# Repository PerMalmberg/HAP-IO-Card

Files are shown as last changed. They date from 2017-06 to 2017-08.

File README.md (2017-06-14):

# HAP I/O Card
Input/output card for use in automation

## Design limits
12V maximum voltage.

## Inputs

### Analog inputs

On-board potentiometers as voltage dividers, allowing for adjustable balanced lines used in alarm systems.
> Will fixed resistors do the trick?

### Digital Inputs

* Optocouplers to provide isolation.
* On-board rotary switch to set number of inputs.
* On-board rotary switch to set unit MQTT address.

> Can it be done so that from a software perspective they are always high/true when 'activated'?

## Outputs

### Digital Outputs

* Optocoupler for low current signals.
* Relays for high-current signals.
* Each output shall have a LED indicating current status.

### General in/outputs

UART flashing connectors.
Debugging pins/JTAG

## On-board LEDs
* Power
* Digital outputs
* Digital inputs

## On-board switches
* OTA-enable

## Power supply
12V DC, with onboard 12->5V DC/DC converter.

## Reference Links

http://www.thebox.myzen.co.uk/Tutorial/Protection.html

* Capacitor calculations
  * http://www.electronics-tutorials.ws/rc/rc_1.html

### Components

#### uC ESP32 thing devboard
  * http://www.mouser.se/new/sparkfun/sparkfun-things/

* Common components
  * 10k ohm 0805 0.5W https://www.digikey.se/product-detail/en/panasonic-electronic-components/ERJ-P06F1002V/P16059CT-ND/3982406
  * 100nF 50V https://www.digikey.se/product-detail/en/avx-corporation/08055C104JAT2A/478-3352-1-ND/930144

* Sensor Inputs
  * I/O Expander ADS1115IDGST https://www.digikey.se/product-detail/en/texas-instruments/ADS1115IDGST/296-24934-1-ND/2123298
  * Varistor 39V 0805 https://www.digikey.se/product-detail/en/epcos-tdk/B72510E250K62/495-7453-1-ND/6073112
  * 2k resistor, 0.5W 0805 https://www.digikey.se/product-detail/en/panasonic-electronic-components/ERJ-P06F2001V/P16065CT-ND/3982412
  * Clamping Shottky diodes 60V, 500mA SOD-123 https://www.digikey.se/product-detail/en/stmicroelectronics/STPS0560Z/497-3787-1-ND/691956
  * Protection diode 3A, SMA https://www.digikey.se/product-detail/en/comchip-technology/CDBA3100-HF/641-1747-1-ND/5400721
  * 100 ohm 1/8W 0805 https://www.digikey.se/product-detail/en/yageo/RC0805FR-07100RL/311-100CRCT-ND/730490
  * 1k ohm 0.5W 0805 https://www.digikey.se/product-detail/en/vishay-dale/CRCW08051K00FKEAHP/541-1.00KTCT-ND/2222852

* Digital I/O
  * I/O Expander MCP23017 https://www.digikey.se/product-detail/en/microchip-technology/MCP23017T-E-SO/MCP23017T-E-SOCT-ND/5358289
  * Input      
    * LED Green Vf 2.2, 20mA https://www.digikey.se/product-detail/en/lumex-opto-components-inc/SML-LXR85GC-TR/67-1557-1-ND/304376
    * LED limiting resistor 56R, 1/8W, 0805 https://www.digikey.se/product-detail/en/panasonic-electronic-components/ERJ-6GEYJ560V/P56ACT-ND/42928
    * 100R discharge resistor https://www.digikey.se/product-detail/en/stackpole-electronics-inc/RNCP0805FTD100R/RNCP0805FTD100RCT-ND/2240548
    * 10uF Electrolytic Cap https://www.digikey.se/product-detail/en/panasonic-electronic-components/EEE-1EA100WR/PCE3895CT-ND/766271
    * 1k 3W, 1%, 2512 https://www.digikey.se/product-detail/en/te-connectivity-passive-product/35221K0FT/A121161CT-ND/5245218
    * LTV-354T https://www.digikey.se/product-detail/en/lite-on-inc/LTV-354T/160-1333-1-ND/385797
  * Output
    * Base resistor 470 http://www.digikey.se/scripts/DkSearch/dksus.dll?Detail&itemSeq=230677912&uq=636330538988753686
    * Kickback protection MBR0580 https://www.digikey.se/product-detail/en/micro-commercial-co/MBR0580-TP/MBR0580-TPMSCT-ND/2423306
    * Transistor https://www.digikey.se/product-detail/en/diodes-incorporated/ZXTN25050DFHTA/ZXTN25050DFHCT-ND/1043605
    * LED RED 20mA, Vf 2V https://www.digikey.se/product-detail/en/lumex-opto-components-inc/SML-LXR85IC-TR/67-1556-1-ND/304374
    * LED limiting resistor 68R, 1/8W, 0805 https://www.digikey.se/product-detail/en/stack  pole-electronics-inc/RMCF0805JT68R0/RMCF0805JT68R0CT-ND/1942537

* Power supply
  * Screw terminal 3-way https://www.digikey.se/product-detail/en/te-connectivity-amp-connectors/282834-3/A98334-ND/1153264
  * LM1086-5V https://www.digikey.se/product-detail/en/texas-instruments/LM1086IT-5.0-NOPB/LM1086IT-5.0-NOPB-ND/363580
  * LM1086-3.3V https://www.digikey.se/product-detail/en/texas-instruments/LM1086IT-3.3-NOPB/LM1086IT-3.3-NOPB-ND/363579
  * 100uF 16V 5mm https://www.digikey.se/product-detail/en/nichicon/ULD1C101MED1TD/493-14722-1-ND/6161730
  * Protection diode MBRS360BT3G http://www.digikey.se/scripts/DkSearch/dksus.dll?Detail&itemSeq=230549693&uq=636329621710320791
  * Zener 5.1V SOD-123 https://www.digikey.se/products/en?keywords=1N4733AW-TPMSCT-ND
  * Signal filter https://www.digikey.se/product-detail/en/murata-electronics-north-america/DSS1NB31H104Q91A/490-9806-1-ND/5018359

https://www.facebook.com/groups/SHgruppen/permalink/662561353933301/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

https://www.facebook.com/groups/SHgruppen/permalink/662561353933301/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

## TODO
Fuse 12V and 3.3V PolyFuse

I2C jumpers to disable devices (development feature)?
ESD protection on in/outputs
Display
Flashing wires
Mounting holes http://www.ebay.com/itm/DIN-Rail-Mounting-Carrier-for-72mm-x-110mm-PCB-Housing-Bracket-/131318695142
I2C expansion header
Test points

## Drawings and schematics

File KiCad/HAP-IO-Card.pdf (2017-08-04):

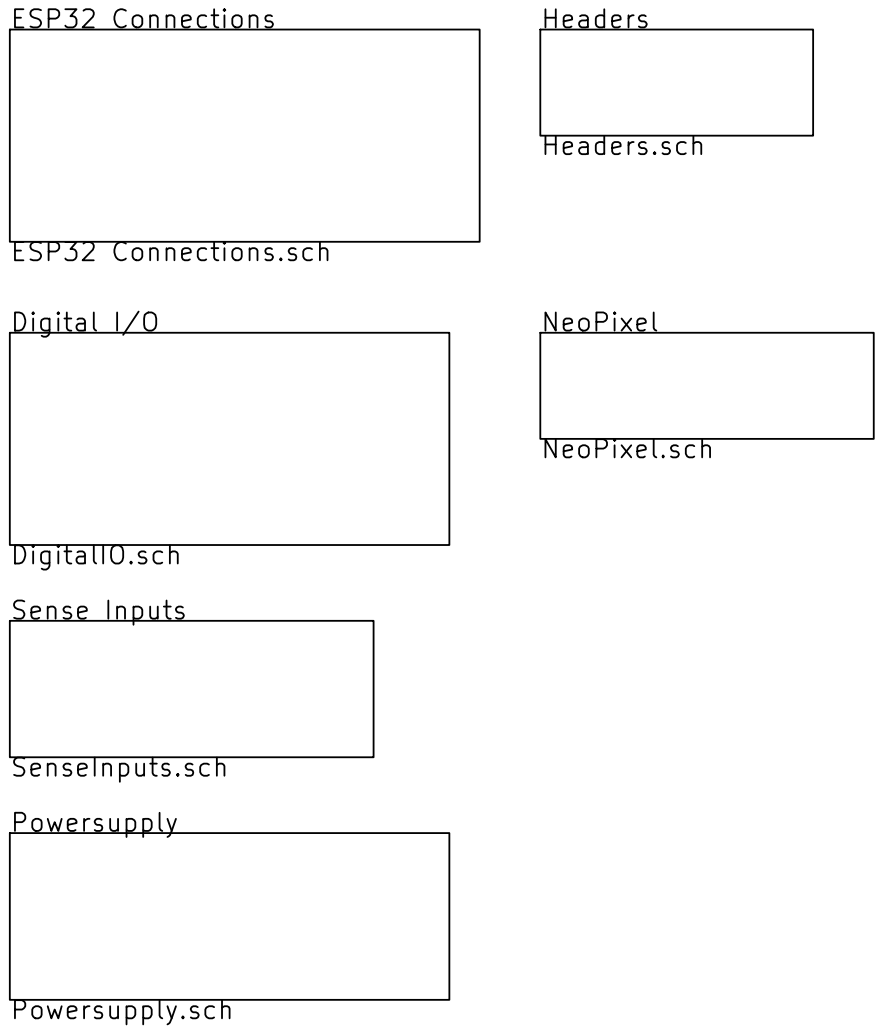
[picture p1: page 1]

https://github.com/PerMalmberg/HAP-IO-Card
File: HAP-IO-Card.sch Sheet: / Author Per Malmberg

Id: 1/7 Title: HAP I/O Card

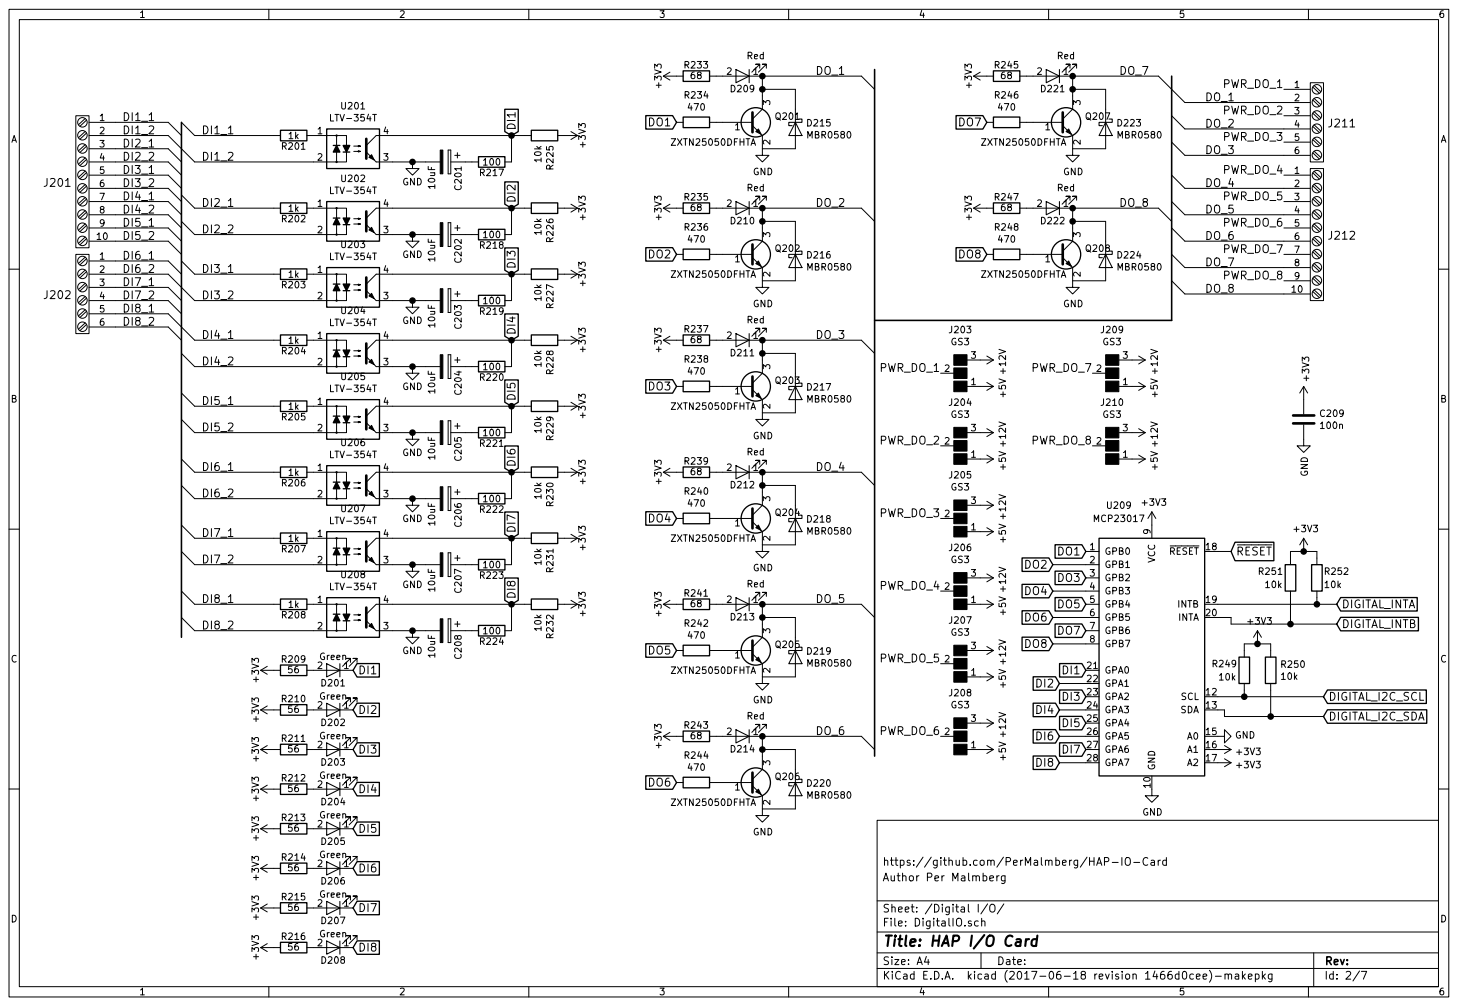
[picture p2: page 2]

1k Select based on input voltage. Max 50mA. 1k should allow for voltages 3.3 - 48V

Sheet: /Digital I/O/
File: DigitalIO.sch
Id: 2/7 Title: HAP I/O Card

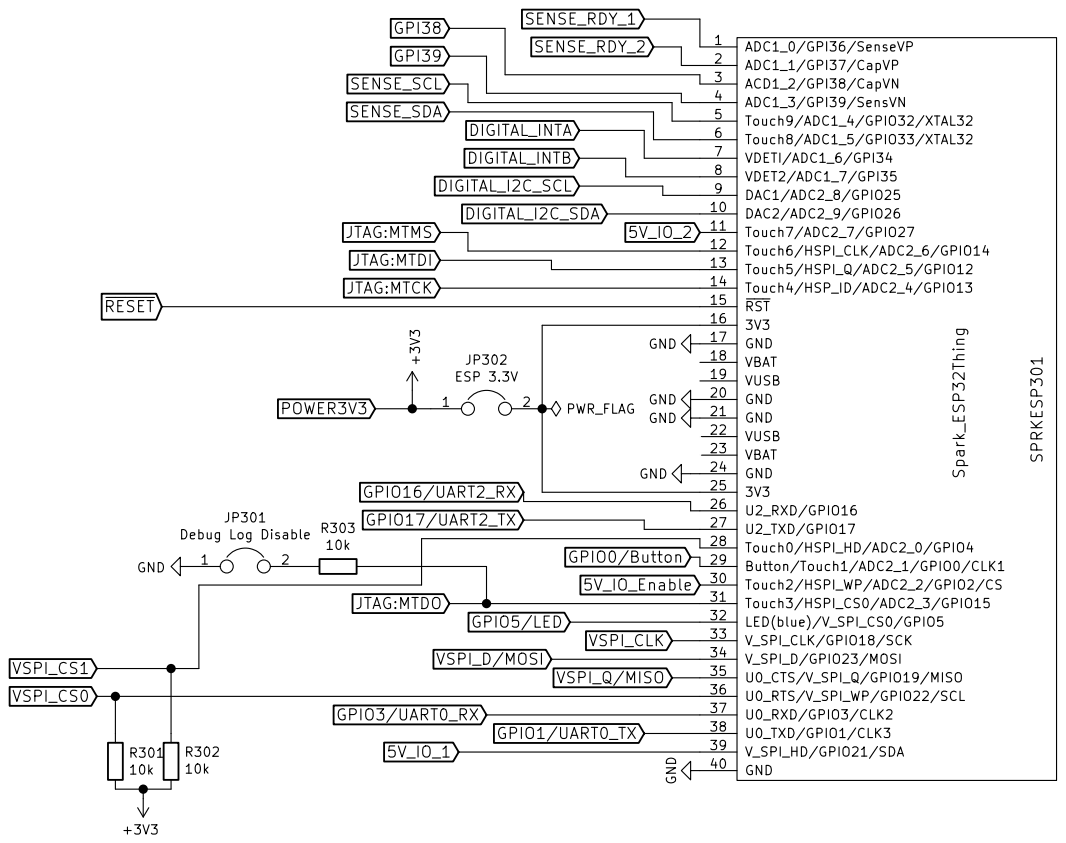
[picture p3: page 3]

The Sparkfun ESP32Thing already
has a 10k pull-up on the reset line.

https://github.com/PerMalmberg/HAP-IO-Card GND GND GND

File: ESP32 Connections.sch Sheet: /ESP32 Connections/ Author Per Malmberg

Id: 3/7 Title: HAP I/O Card

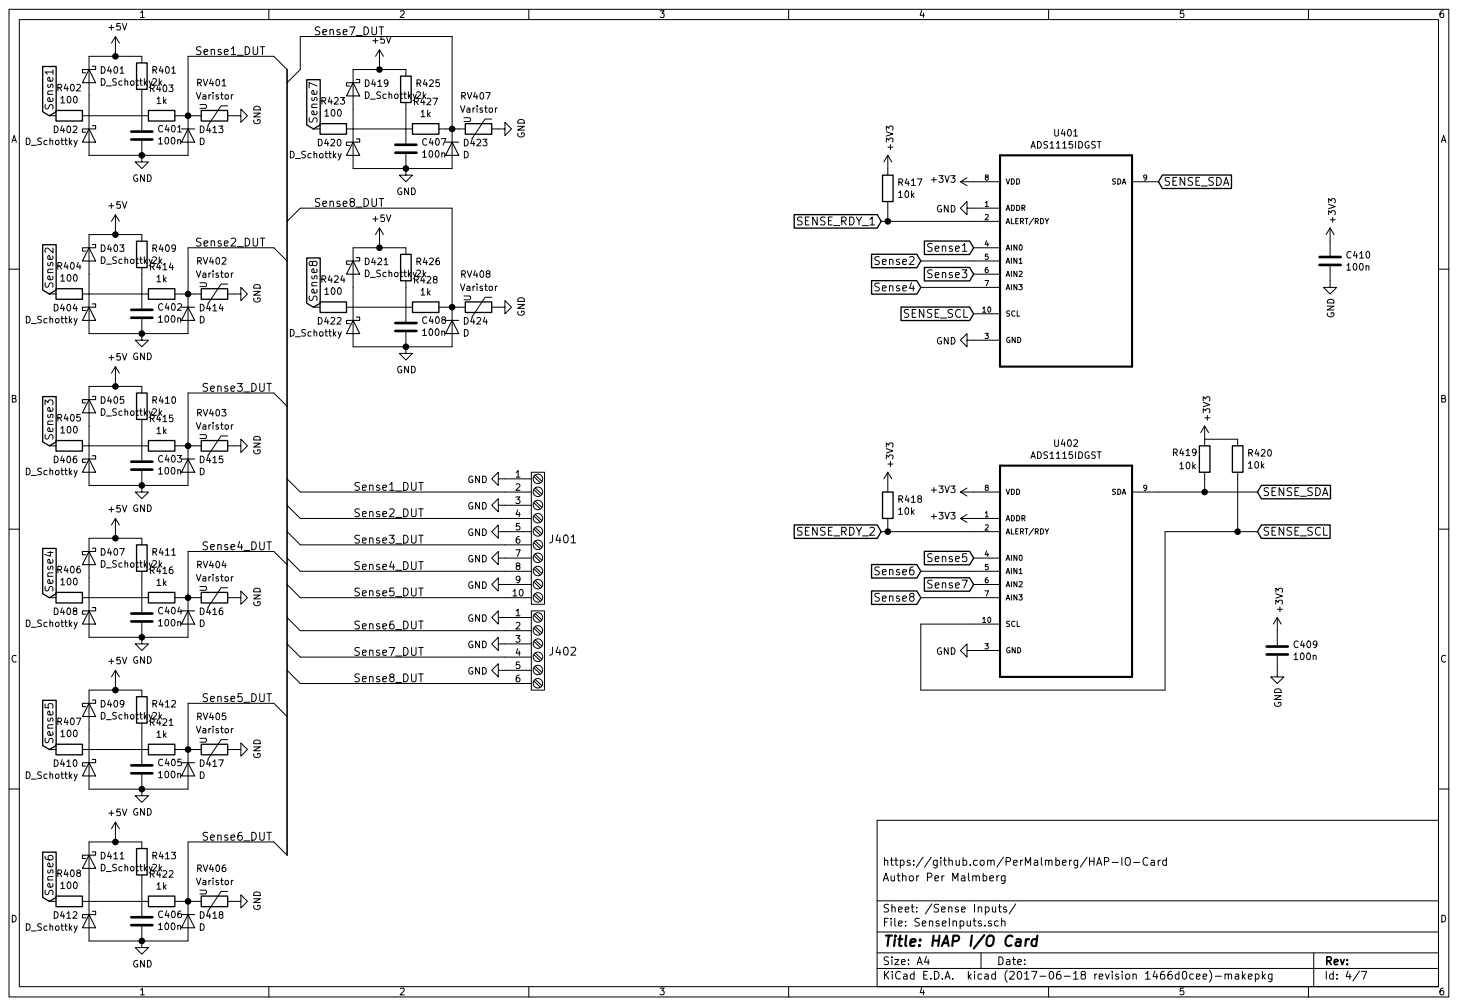
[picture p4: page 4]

https://github.com/PerMalmberg/HAP-IO-Card
Author Per Malmberg

Sheet: /Sense Inputs/
File: SenseInputs.sch
Id: 4/7 Title: HAP I/O Card

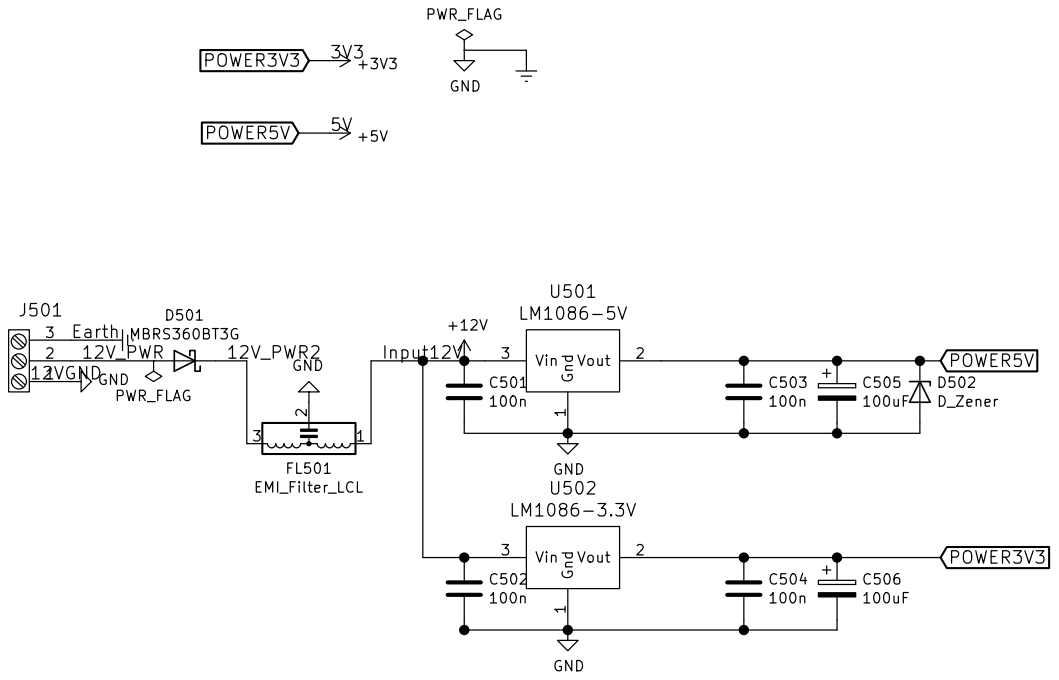
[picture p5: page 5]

+12V Line filter Murata DSN6 Series

prevent rail from going
above nominal value
due to voltage input
from sensor inputs.

https://github.com/PerMalmberg/HAP-IO-Card
Author Per Malmberg

Sheet: /Powersupply/
File: Powersupply.sch
Id: 5/7 Title: HAP I/O Card

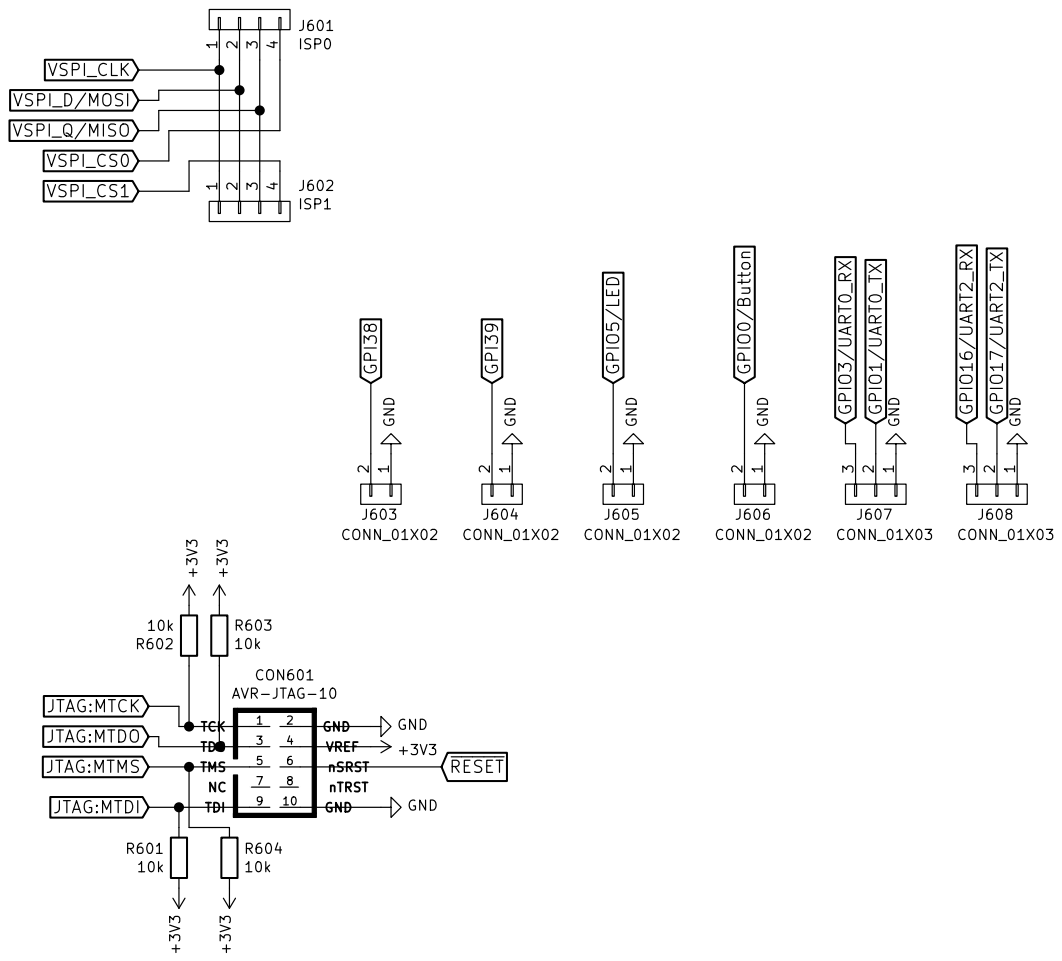
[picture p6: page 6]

https://github.com/PerMalmberg/HAP-IO-Card
File: Headers.sch Sheet: /Headers/ Author Per Malmberg

Id: 6/7 Title: HAP I/O Card

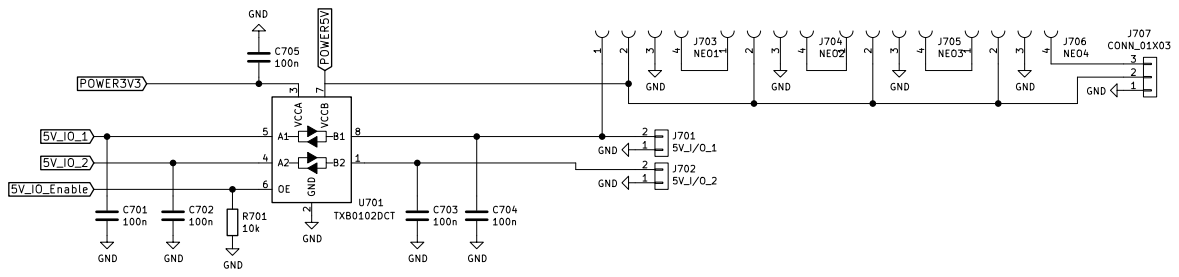
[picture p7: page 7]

File: NeoPixel.sch Sheet: /NeoPixel/ Author Per Malmberg

Id: 7/7 Title: HAP I/O Card

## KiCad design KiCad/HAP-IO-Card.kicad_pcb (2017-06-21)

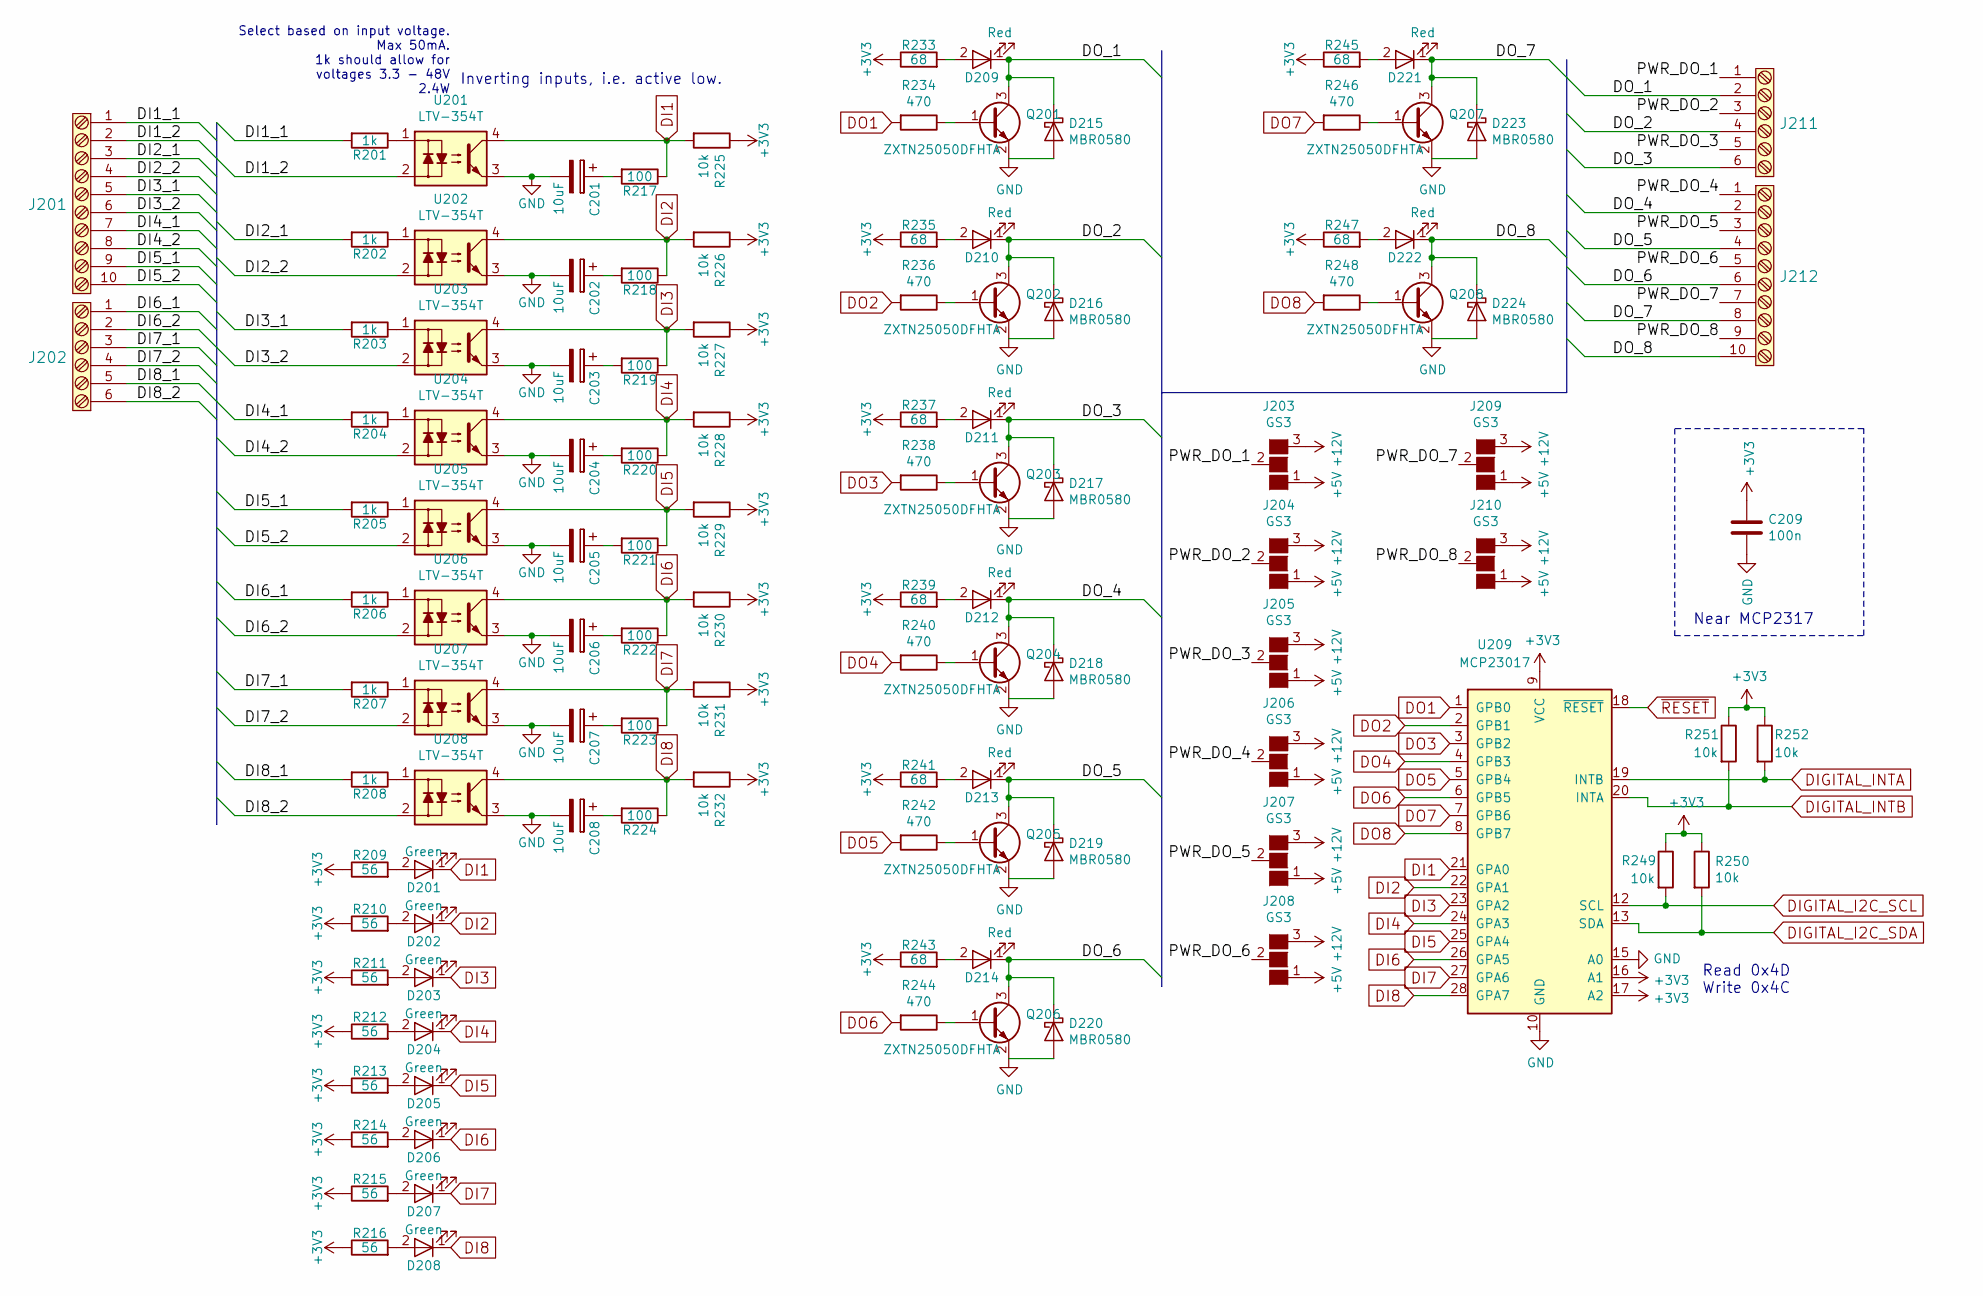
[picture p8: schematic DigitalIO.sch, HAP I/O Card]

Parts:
C201, C202, C203, C204, C205, C206, C207, C208: 10uF; CP_Elec_5x4.5
C209: 100n; C_0805
D201, D202, D203, D204, D205, D206, D207, D208: Green; LED_0805
D209, D210, D211, D212, D213, D214, D221, D222: Red; LED_0805
D215, D216, D217, D218, D219, D220, D223, D224: MBR0580; D_SOD-123
J201, J212: TE_Connectivity_1-282834-0
J202, J211: TE_Connectivity_282834-6
J203, J204, J205, J206, J207, J208, J209, J210: GS3
Q201, Q202, Q203, Q204, Q205, Q206, Q207, Q208: ZXTN25050DFHTA; SOT-23
R201, R202, R203, R204, R205, R206, R207, R208: 1k; R_2512
R209, R210, R211, R212, R213, R214, R215, R216: 56; R_0805
R217, R218, R219, R220, R221, R222, R223, R224: 100; R_0805
R225, R226, R227, R228, R229, R230, R231, R232, R249, R250, R251, R252: 10k; R_0805
R233, R235, R237, R239, R241, R243, R245, R247: 68; R_0805
R234, R236, R238, R240, R242, R244, R246, R248: 470; R_0805
U201, U202, U203, U204, U205, U206, U207, U208: LTV-354T; SO-4_4.4x3.6mm_Pitch2.54mm
U209: MCP23017; SOIC-28W_7.5x17.9mm_Pitch1.27mm

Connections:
+12V: J203.3 (G3), J204.3 (G3), J205.3 (G3), J206.3 (G3), J207.3 (G3), J208.3 (G3), J209.3 (G3), J210.3 (G3); also elsewhere on the board
/Digital I/O/DI1_1: J201.1, R201.2
/Digital I/O/DI1_2: J201.2, U201.2
/Digital I/O/DI2_1: J201.3, R202.2
/Digital I/O/DI2_2: J201.4, U202.2
/Digital I/O/DI3_1: J201.5, R203.2
/Digital I/O/DI3_2: J201.6, U203.2
/Digital I/O/DI4_1: J201.7, R204.2
/Digital I/O/DI4_2: J201.8, U204.2
/Digital I/O/DI5_1: J201.9, R205.2
/Digital I/O/DI5_2: J201.10, U205.2
/Digital I/O/DI6_1: J202.1, R206.2
/Digital I/O/DI6_2: J202.2, U206.2
/Digital I/O/DI7_1: J202.3, R207.2
/Digital I/O/DI7_2: J202.4, U207.2
/Digital I/O/DI8_1: J202.5, R208.2
/Digital I/O/DI8_2: J202.6, U208.2
/Digital I/O/DO_1: D209.1 (K), D215.1 (K), J211.2, Q201.3 (C)
/Digital I/O/DO_2: D210.1 (K), D216.1 (K), J211.4, Q202.3 (C)
/Digital I/O/DO_3: D211.1 (K), D217.1 (K), J211.6, Q203.3 (C)
/Digital I/O/DO_4: D212.1 (K), D218.1 (K), J212.2, Q204.3 (C)
/Digital I/O/DO_5: D213.1 (K), D219.1 (K), J212.4, Q205.3 (C)
/Digital I/O/DO_6: D214.1 (K), D220.1 (K), J212.6, Q206.3 (C)
/Digital I/O/DO_7: D221.1 (K), D223.1 (K), J212.8, Q207.3 (C)
/Digital I/O/DO_8: D222.1 (K), D224.1 (K), J212.10, Q208.3 (C)
/Digital I/O/PWR_DO_1: J203.2 (G2), J211.1
/Digital I/O/PWR_DO_2: J204.2 (G2), J211.3
/Digital I/O/PWR_DO_3: J205.2 (G2), J211.5
/Digital I/O/PWR_DO_4: J206.2 (G2), J212.1
/Digital I/O/PWR_DO_5: J207.2 (G2), J212.3
/Digital I/O/PWR_DO_6: J208.2 (G2), J212.5
/Digital I/O/PWR_DO_7: J209.2 (G2), J212.7
/Digital I/O/PWR_DO_8: J210.2 (G2), J212.9
DI1: D201.1 (K), R217.1, R225.2, U201.4, U209.21 (GPA0)
DI2: D202.1 (K), R218.1, R226.2, U202.4, U209.22 (GPA1)
DI3: D203.1 (K), R219.1, R227.2, U203.4, U209.23 (GPA2)
DI4: D204.1 (K), R220.1, R228.2, U204.4, U209.24 (GPA3)
DI5: D205.1 (K), R221.1, R229.2, U205.4, U209.25 (GPA4)
DI6: D206.1 (K), R222.1, R230.2, U206.4, U209.26 (GPA5)
DI7: D207.1 (K), R223.1, R231.2, U207.4, U209.27 (GPA6)
DI8: D208.1 (K), R224.1, R232.2, U208.4, U209.28 (GPA7)
DIGITAL_I2C_SCL: R249.2, U209.12 (SCL); also elsewhere on the board
DIGITAL_I2C_SDA: R250.2, U209.13 (SDA); also elsewhere on the board
DIGITAL_INTA: R252.2, U209.19 (INTB); also elsewhere on the board
DIGITAL_INTB: R251.2, U209.20 (INTA); also elsewhere on the board
DO1: R234.2, U209.1 (GPB0)
DO2: R236.2, U209.2 (GPB1)
DO3: R238.2, U209.3 (GPB2)
DO4: R240.2, U209.4 (GPB3)
DO5: R242.2, U209.5 (GPB4)
DO6: R244.2, U209.6 (GPB5)
DO7: R246.2, U209.7 (GPB6)
DO8: R248.2, U209.8 (GPB7)
Earth: C201.2, C202.2, C203.2, C204.2, C205.2, C206.2, C207.2, C208.2, C209.2, D215.2 (A), D216.2 (A), D217.2 (A), D218.2 (A), D219.2 (A), D220.2 (A), D223.2 (A), D224.2 (A), Q201.2 (E), Q202.2 (E), Q203.2 (E), Q204.2 (E), Q205.2 (E), Q206.2 (E), Q207.2 (E), Q208.2 (E), U201.3, U202.3, U203.3, U204.3, U205.3, U206.3, U207.3, U208.3, U209.10 (GND), U209.15 (A0); also elsewhere on the board
unnamed: C201.1, R217.2
unnamed: C202.1, R218.2
unnamed: C203.1, R219.2
unnamed: C204.1, R220.2
unnamed: C205.1, R221.2
unnamed: C206.1, R222.2
unnamed: C207.1, R223.2
unnamed: C208.1, R224.2
unnamed: D201.2 (A), R209.2
unnamed: D202.2 (A), R210.2
unnamed: D203.2 (A), R211.2
unnamed: D204.2 (A), R212.2
unnamed: D205.2 (A), R213.2
unnamed: D206.2 (A), R214.2
unnamed: D207.2 (A), R215.2
unnamed: D208.2 (A), R216.2
unnamed: D209.2 (A), R233.2
unnamed: D210.2 (A), R235.2
unnamed: D211.2 (A), R237.2
unnamed: D212.2 (A), R239.2
unnamed: D213.2 (A), R241.2
unnamed: D214.2 (A), R243.2
unnamed: D221.2 (A), R245.2
unnamed: D222.2 (A), R247.2
unnamed: Q201.1 (B), R234.1
unnamed: Q202.1 (B), R236.1
unnamed: Q203.1 (B), R238.1
unnamed: Q204.1 (B), R240.1
unnamed: Q205.1 (B), R242.1
unnamed: Q206.1 (B), R244.1
unnamed: Q207.1 (B), R246.1
unnamed: Q208.1 (B), R248.1
unnamed: R201.1, U201.1
unnamed: R202.1, U202.1
unnamed: R203.1, U203.1
unnamed: R204.1, U204.1
unnamed: R205.1, U205.1
unnamed: R206.1, U206.1
unnamed: R207.1, U207.1
unnamed: R208.1, U208.1
POWER3V3: C209.1, R209.1, R210.1, R211.1, R212.1, R213.1, R214.1, R215.1, R216.1, R225.1, R226.1, R227.1, R228.1, R229.1, R230.1, R231.1, R232.1, R233.1, R235.1, R237.1, R239.1, R241.1, R243.1, R245.1, R247.1, R249.1, R250.1, R251.1, R252.1, U209.9 (VCC), U209.16 (A1), U209.17 (A2); also elsewhere on the board
POWER5V: J203.1 (G1), J204.1 (G1), J205.1 (G1), J206.1 (G1), J207.1 (G1), J208.1 (G1), J209.1 (G1), J210.1 (G1); also elsewhere on the board
~RESET: U209.18 (~RESET); also elsewhere on the board

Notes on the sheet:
Select based on input voltage. Max 50mA. 1k should allow for voltages 3.3 - 48V 2.4W
Inverting inputs, i.e. active low.
Read 0x4D Write 0x4C
Near MCP2317

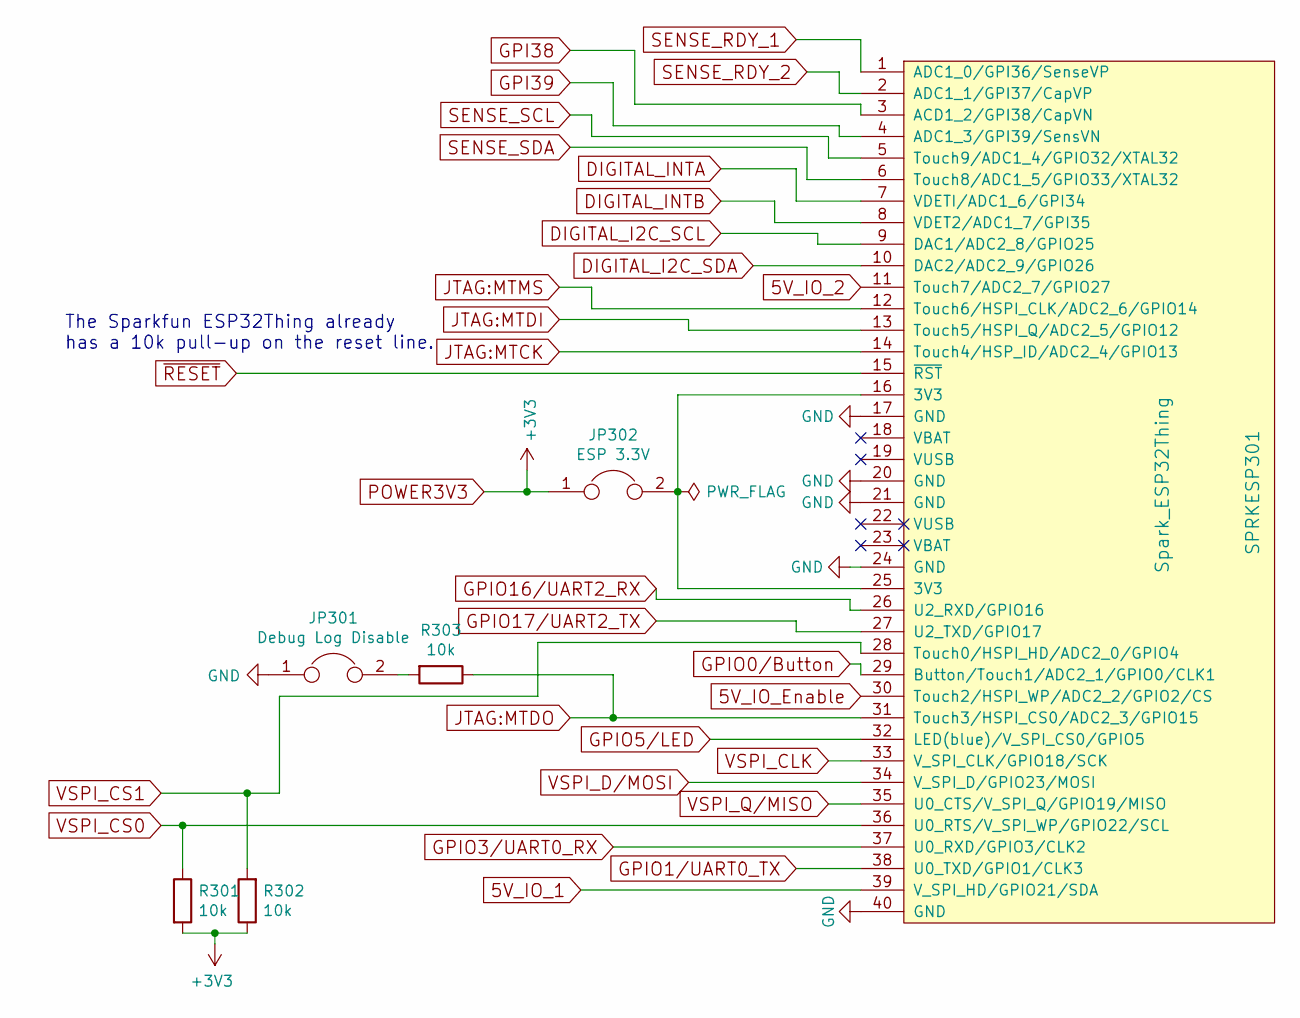
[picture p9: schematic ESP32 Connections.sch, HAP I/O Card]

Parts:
JP301: Debug Log Disable; Pin_Header_Straight_1x02_Pitch2.54mm
JP302: ESP 3.3V; Pin_Header_Straight_1x02_Pitch2.54mm
R301, R302, R303: 10k; R_0805
SPRKESP301: Spark_ESP32Thing; Sparkfun_ESP32Thing

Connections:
5V_IO_1: SPRKESP301.39 (V_SPI_HD/GPIO21/SDA); also elsewhere on the board
5V_IO_2: SPRKESP301.11 (Touch7/ADC2_7/GPIO27); also elsewhere on the board
5V_IO_Enable: SPRKESP301.30 (Touch2/HSPI_WP/ADC2_2/GPIO2/CS); also elsewhere on the board
DIGITAL_I2C_SCL: SPRKESP301.9 (DAC1/ADC2_8/GPIO25); also elsewhere on the board
DIGITAL_I2C_SDA: SPRKESP301.10 (DAC2/ADC2_9/GPIO26); also elsewhere on the board
DIGITAL_INTA: SPRKESP301.7 (VDETI/ADC1_6/GPI34); also elsewhere on the board
DIGITAL_INTB: SPRKESP301.8 (VDET2/ADC1_7/GPI35); also elsewhere on the board
Earth: JP301.1, SPRKESP301.17 (GND), SPRKESP301.20 (GND), SPRKESP301.21 (GND), SPRKESP301.24 (GND), SPRKESP301.40 (GND); also elsewhere on the board
GPI38: SPRKESP301.3 (ACD1_2/GPI38/CapVN); also elsewhere on the board
GPI39: SPRKESP301.4 (ADC1_3/GPI39/SensVN); also elsewhere on the board
GPIO0/Button: SPRKESP301.29 (Button/Touch1/ADC2_1/GPIO0/CLK1); also elsewhere on the board
GPIO1/UART0_TX: SPRKESP301.38 (U0_TXD/GPIO1/CLK3); also elsewhere on the board
GPIO3/UART0_RX: SPRKESP301.37 (U0_RXD/GPIO3/CLK2); also elsewhere on the board
GPIO5/LED: SPRKESP301.32 (LED(blue)/V_SPI_CS0/GPIO5); also elsewhere on the board
GPIO16/UART2_RX: SPRKESP301.26 (U2_RXD/GPIO16); also elsewhere on the board
GPIO17/UART2_TX: SPRKESP301.27 (U2_TXD/GPIO17); also elsewhere on the board
JTAG:MTCK: SPRKESP301.14 (Touch4/HSP_ID/ADC2_4/GPIO13); also elsewhere on the board
JTAG:MTDI: SPRKESP301.13 (Touch5/HSPI_Q/ADC2_5/GPIO12); also elsewhere on the board
JTAG:MTDO: R303.1, SPRKESP301.31 (Touch3/HSPI_CS0/ADC2_3/GPIO15); also elsewhere on the board
JTAG:MTMS: SPRKESP301.12 (Touch6/HSPI_CLK/ADC2_6/GPIO14); also elsewhere on the board
unnamed: JP301.2, R303.2
unnamed: JP302.2, SPRKESP301.16 (3V3), SPRKESP301.25 (3V3)
POWER3V3: JP302.1, R301.2, R302.1; also elsewhere on the board
SENSE_RDY_1: SPRKESP301.1 (ADC1_0/GPI36/SenseVP); also elsewhere on the board
SENSE_RDY_2: SPRKESP301.2 (ADC1_1/GPI37/CapVP); also elsewhere on the board
SENSE_SCL: SPRKESP301.5 (Touch9/ADC1_4/GPIO32/XTAL32); also elsewhere on the board
SENSE_SDA: SPRKESP301.6 (Touch8/ADC1_5/GPIO33/XTAL32); also elsewhere on the board
VSPI_CLK: SPRKESP301.33 (V_SPI_CLK/GPIO18/SCK); also elsewhere on the board
VSPI_CS0: R301.1, SPRKESP301.36 (U0_RTS/V_SPI_WP/GPIO22/SCL); also elsewhere on the board
VSPI_CS1: R302.2, SPRKESP301.28 (Touch0/HSPI_HD/ADC2_0/GPIO4); also elsewhere on the board
VSPI_D/MOSI: SPRKESP301.34 (V_SPI_D/GPIO23/MOSI); also elsewhere on the board
VSPI_Q/MISO: SPRKESP301.35 (U0_CTS/V_SPI_Q/GPIO19/MISO); also elsewhere on the board
~RESET: SPRKESP301.15 (~RST); also elsewhere on the board

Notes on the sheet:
The Sparkfun ESP32Thing already has a 10k pull-up on the reset line.

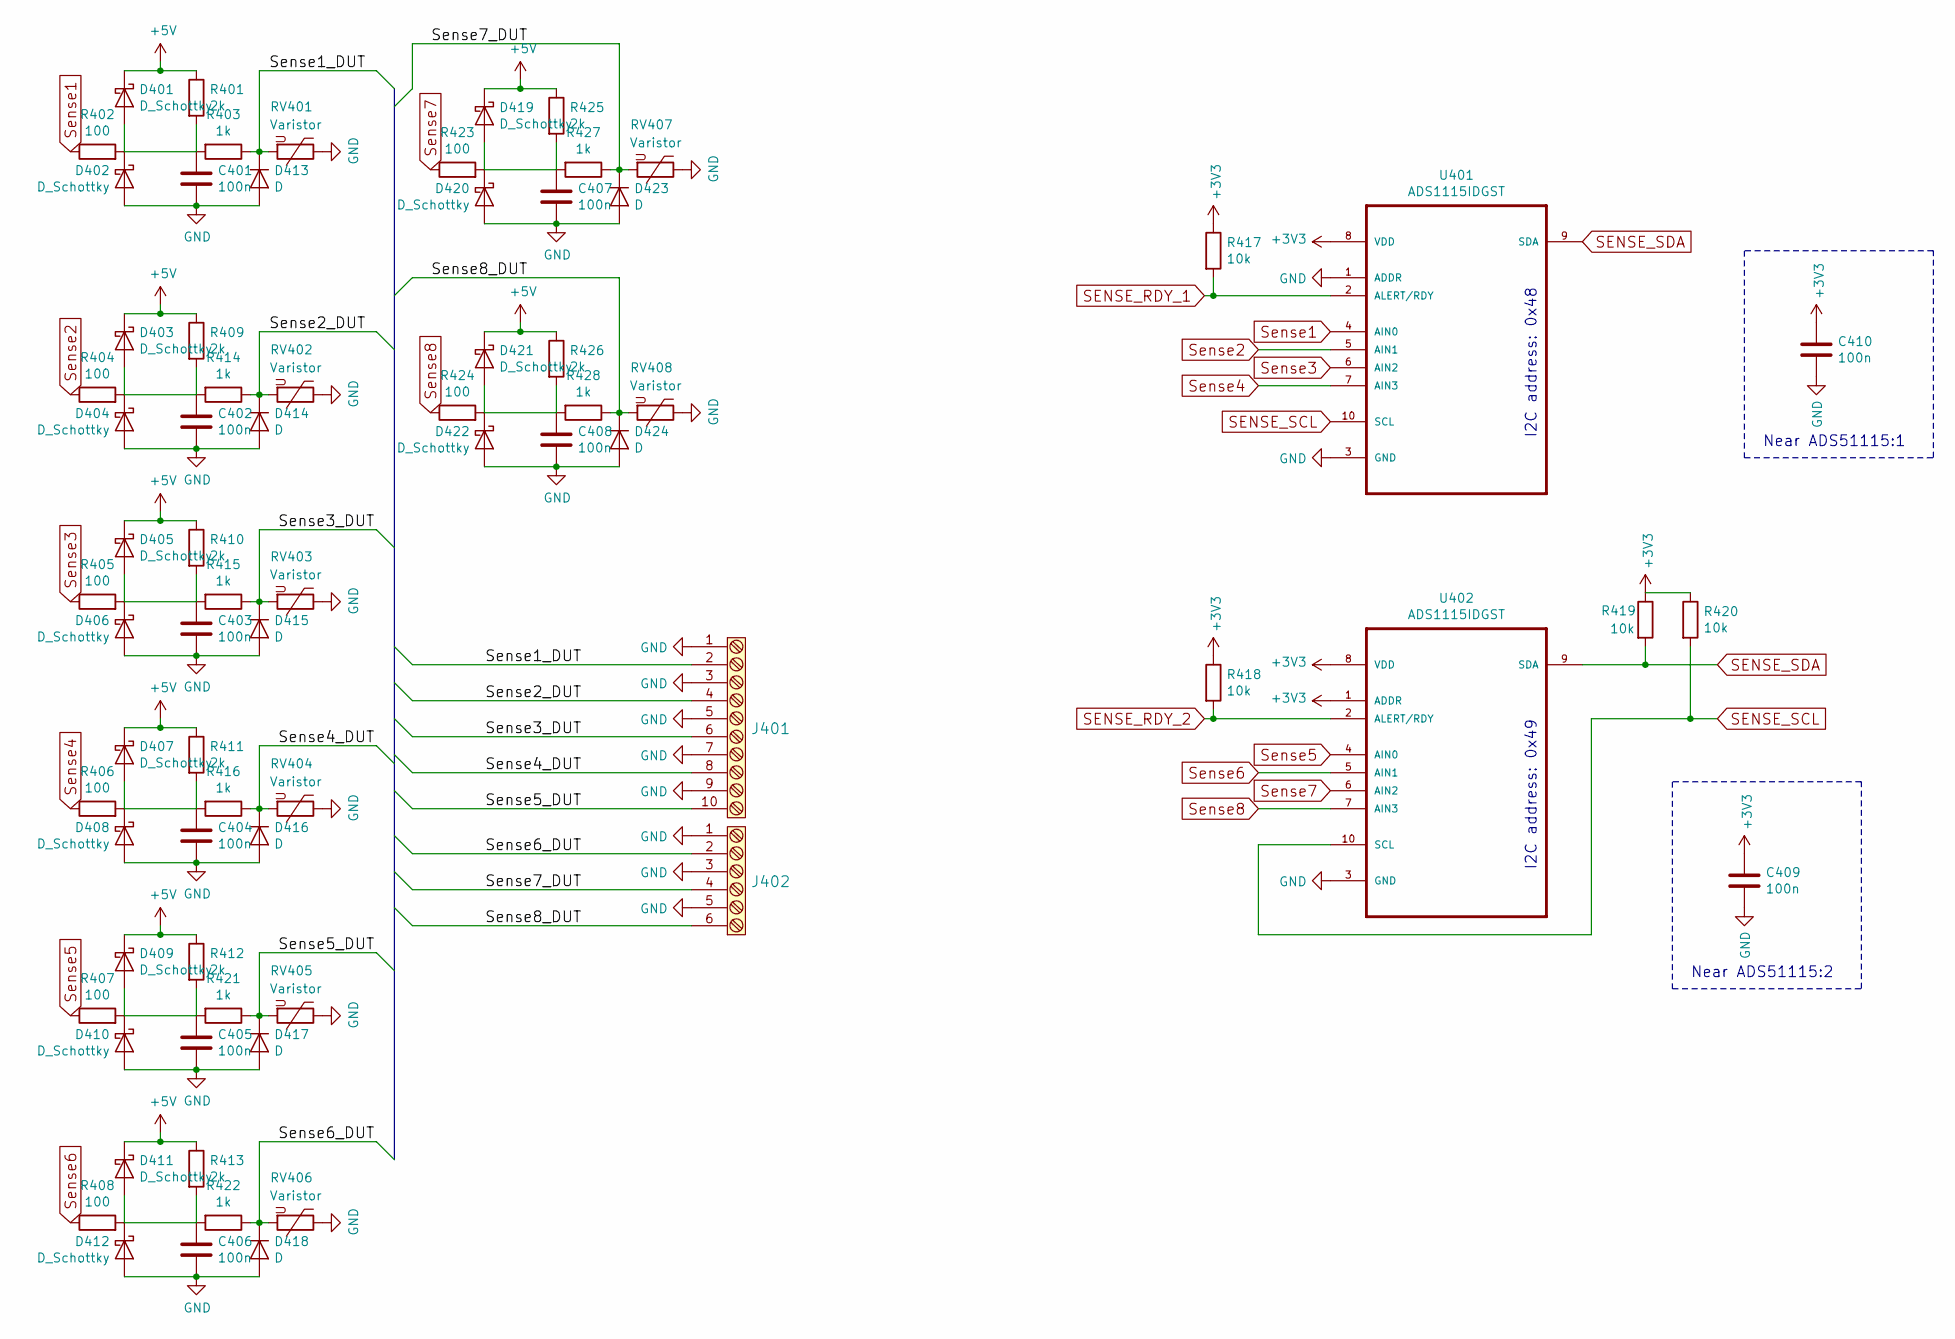
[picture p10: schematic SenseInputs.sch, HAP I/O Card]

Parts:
C401, C402, C403, C404, C405, C406, C407, C408, C409, C410: 100n; C_0805
D401, D402, D403, D404, D405, D406, D407, D408, D409, D410, D411, D412, D419, D420, D421, D422: D_Schottky; D_SOD-123
D413, D414, D415, D416, D417, D418, D423, D424: D; D_SMA
J401: TE_Connectivity_1-282834-0
J402: TE_Connectivity_282834-6
R401, R409, R410, R411, R412, R413, R425, R426: 2k; R_0805
R402, R404, R405, R406, R407, R408, R423, R424: 100; R_0805
R403, R414, R415, R416, R421, R422, R427, R428: 1k; R_0805
R417, R418, R419, R420: 10k; R_0805
RV401, RV402, RV403, RV404, RV405, RV406, RV407, RV408: Varistor; R_0805
U401, U402: ADS1115IDGST; SOP50P490X110-10N

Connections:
/Sense Inputs/Sense1_DUT: D413.1 (K), J401.2, R403.1, RV401.2
/Sense Inputs/Sense2_DUT: D414.1 (K), J401.4, R414.1, RV402.2
/Sense Inputs/Sense3_DUT: D415.1 (K), J401.6, R415.1, RV403.2
/Sense Inputs/Sense4_DUT: D416.1 (K), J401.8, R416.1, RV404.2
/Sense Inputs/Sense5_DUT: D417.1 (K), J401.10, R421.1, RV405.2
/Sense Inputs/Sense6_DUT: D418.1 (K), J402.2, R422.1, RV406.2
/Sense Inputs/Sense7_DUT: D423.1 (K), J402.4, R427.1, RV407.2
/Sense Inputs/Sense8_DUT: D424.1 (K), J402.6, R428.1, RV408.2
Earth: C401.1, C402.1, C403.1, C404.1, C405.1, C406.1, C407.1, C408.1, C409.2, C410.2, D402.2 (A), D404.2 (A), D406.2 (A), D408.2 (A), D410.2 (A), D412.2 (A), D413.2 (A), D414.2 (A), D415.2 (A), D416.2 (A), D417.2 (A), D418.2 (A), D420.2 (A), D422.2 (A), D423.2 (A), D424.2 (A), J401.1, J401.3, J401.5, J401.7, J401.9, J402.1, J402.3, J402.5, RV401.1, RV402.1, RV403.1, RV404.1, RV405.1, RV406.1, RV407.1, RV408.1, U401.1 (ADDR), U401.3 (GND), U402.3 (GND); also elsewhere on the board
unnamed: C401.2, D401.2 (A), D402.1 (K), R401.2, R402.2, R403.2
unnamed: C402.2, D403.2 (A), D404.1 (K), R404.2, R409.2, R414.2
unnamed: C403.2, D405.2 (A), D406.1 (K), R405.2, R410.2, R415.2
unnamed: C404.2, D407.2 (A), D408.1 (K), R406.2, R411.2, R416.2
unnamed: C405.2, D409.2 (A), D410.1 (K), R407.2, R412.2, R421.2
unnamed: C406.2, D411.2 (A), D412.1 (K), R408.2, R413.2, R422.2
unnamed: C407.2, D419.2 (A), D420.1 (K), R423.2, R425.2, R427.2
unnamed: C408.2, D421.2 (A), D422.1 (K), R424.2, R426.2, R428.2
POWER3V3: C409.1, C410.1, R417.1, R418.1, R419.1, R420.1, U401.8 (VDD), U402.1 (ADDR), U402.8 (VDD); also elsewhere on the board
POWER5V: D401.1 (K), D403.1 (K), D405.1 (K), D407.1 (K), D409.1 (K), D411.1 (K), D419.1 (K), D421.1 (K), R401.1, R409.1, R410.1, R411.1, R412.1, R413.1, R425.1, R426.1; also elsewhere on the board
SENSE_RDY_1: R417.2, U401.2 (ALERT/RDY); also elsewhere on the board
SENSE_RDY_2: R418.2, U402.2 (ALERT/RDY); also elsewhere on the board
SENSE_SCL: R420.2, U401.10 (SCL), U402.10 (SCL); also elsewhere on the board
SENSE_SDA: R419.2, U401.9 (SDA), U402.9 (SDA); also elsewhere on the board
Sense1: R402.1, U401.4 (AIN0)
Sense2: R404.1, U401.5 (AIN1)
Sense3: R405.1, U401.6 (AIN2)
Sense4: R406.1, U401.7 (AIN3)
Sense5: R407.1, U402.4 (AIN0)
Sense6: R408.1, U402.5 (AIN1)
Sense7: R423.1, U402.6 (AIN2)
Sense8: R424.1, U402.7 (AIN3)

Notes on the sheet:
Near ADS51115:1
Near ADS51115:2
I2C address: 0x48
I2C address: 0x49

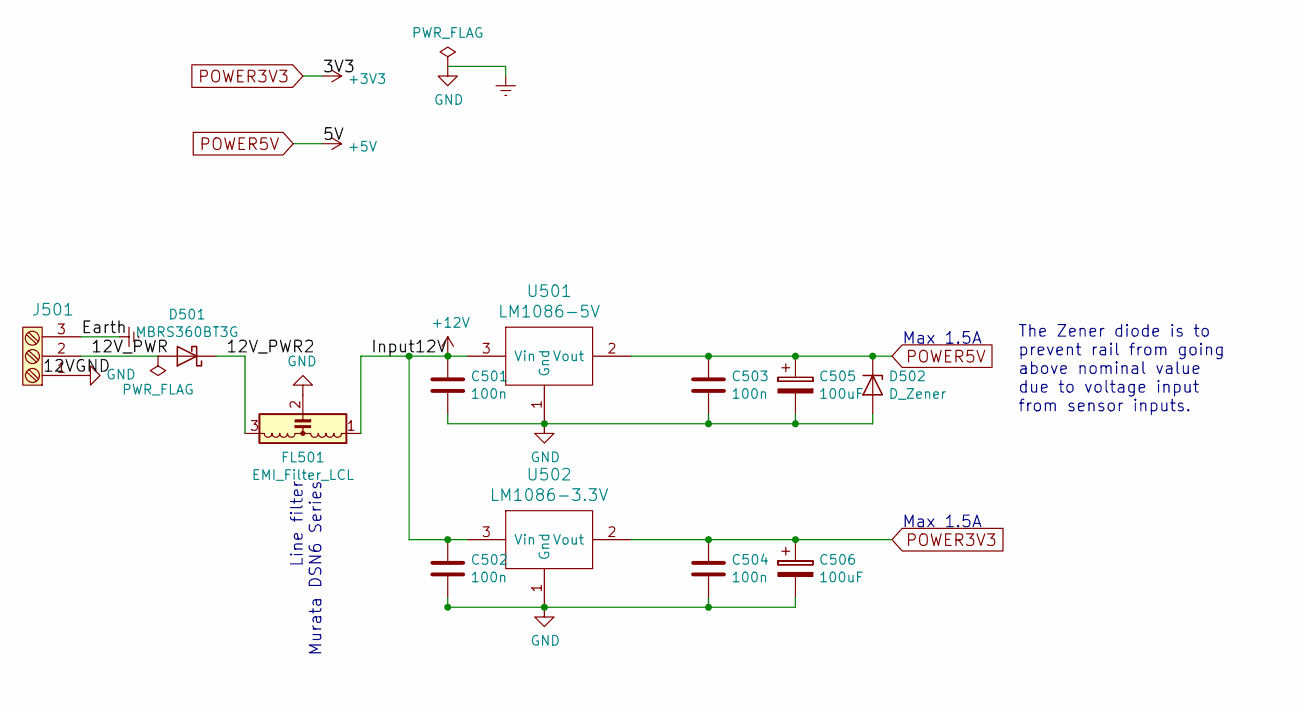
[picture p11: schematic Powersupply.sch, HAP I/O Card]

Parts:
C501, C502, C503, C504: 100n; C_0805
C505, C506: 100uF; CP_Radial_D6.3mm_P2.50mm
D501: MBRS360BT3G; D_SMB
D502: D_Zener; D_SOD-123
FL501: EMI_Filter_LCL; Pin_Header_Straight_1x03_Pitch2.54mm
J501: TE_Connectivity_282834-3
U501: LM1086-5V; TO-220_Vertical
U502: LM1086-3.3V; TO-220_Vertical

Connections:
+12V: C501.1, C502.1, FL501.1, U501.3 (Vin), U502.3 (Vin); also elsewhere on the board
/Powersupply/12V_PWR: D501.2 (A), J501.2
/Powersupply/12V_PWR2: D501.1 (K), FL501.3
Earth: C501.2, C502.2, C503.2, C504.2, C505.2, C506.2, D502.2 (A), FL501.2, J501.1, J501.3, U501.1 (Gnd), U502.1 (Gnd); also elsewhere on the board
POWER3V3: C504.1, C506.1, U502.2 (Vout); also elsewhere on the board
POWER5V: C503.1, C505.1, D502.1 (K), U501.2 (Vout); also elsewhere on the board

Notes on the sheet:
Max 1.5A
Line filter Murata DSN6 Series
The Zener diode is to prevent rail from going above nominal value due to voltage input from sensor inputs.

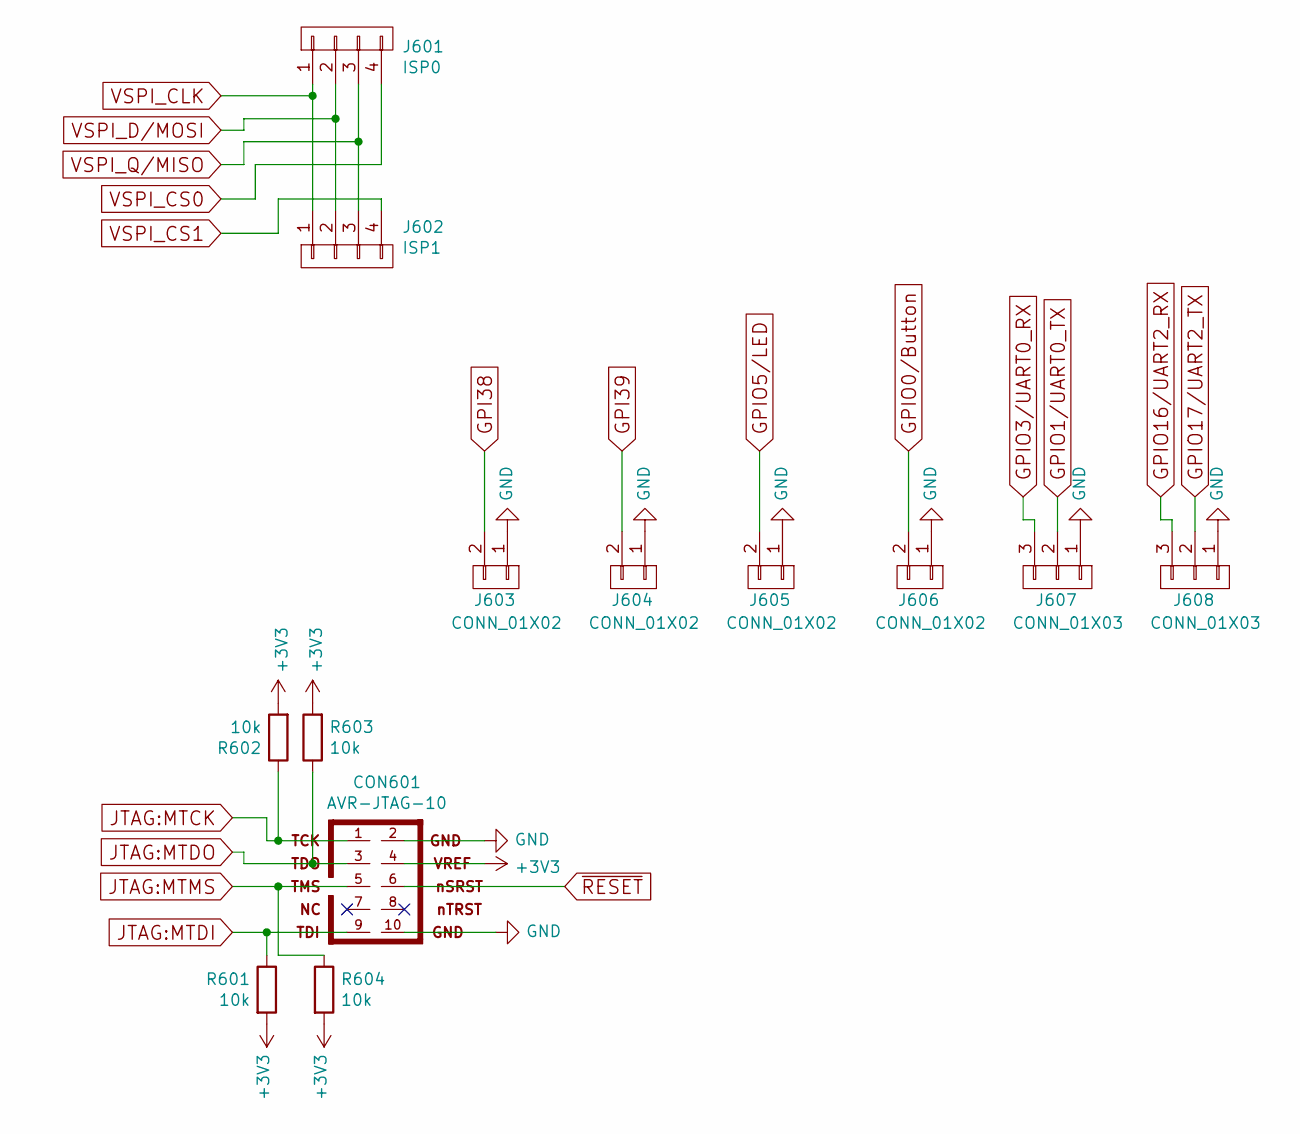
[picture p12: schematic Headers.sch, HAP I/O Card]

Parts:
CON601: AVR-JTAG-10; Pin_Header_Straight_2x05_Pitch2.54mm
J601: ISP0; Pin_Header_Straight_1x04_Pitch2.54mm
J602: ISP1; Pin_Header_Straight_1x04_Pitch2.54mm
J603, J604, J605, J606: CONN_01X02; Pin_Header_Straight_1x02_Pitch2.54mm
J607, J608: CONN_01X03; Pin_Header_Straight_1x03_Pitch2.54mm
R601, R602, R603, R604: 10k; R_0805

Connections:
Earth: CON601.2, CON601.10, J603.1, J604.1, J605.1, J606.1, J607.1, J608.1; also elsewhere on the board
GPI38: J603.2; also elsewhere on the board
GPI39: J604.2; also elsewhere on the board
GPIO0/Button: J606.2; also elsewhere on the board
GPIO1/UART0_TX: J607.2; also elsewhere on the board
GPIO3/UART0_RX: J607.3; also elsewhere on the board
GPIO5/LED: J605.2; also elsewhere on the board
GPIO16/UART2_RX: J608.3; also elsewhere on the board
GPIO17/UART2_TX: J608.2; also elsewhere on the board
JTAG:MTCK: CON601.1, R602.1; also elsewhere on the board
JTAG:MTDI: CON601.9, R601.1; also elsewhere on the board
JTAG:MTDO: CON601.3, R603.1; also elsewhere on the board
JTAG:MTMS: CON601.5, R604.1; also elsewhere on the board
POWER3V3: CON601.4, R601.2, R602.2, R603.2, R604.2; also elsewhere on the board
VSPI_CLK: J601.1, J602.1; also elsewhere on the board
VSPI_CS0: J601.4; also elsewhere on the board
VSPI_CS1: J602.4; also elsewhere on the board
VSPI_D/MOSI: J601.2, J602.2; also elsewhere on the board
VSPI_Q/MISO: J601.3, J602.3; also elsewhere on the board
~RESET: CON601.6; also elsewhere on the board

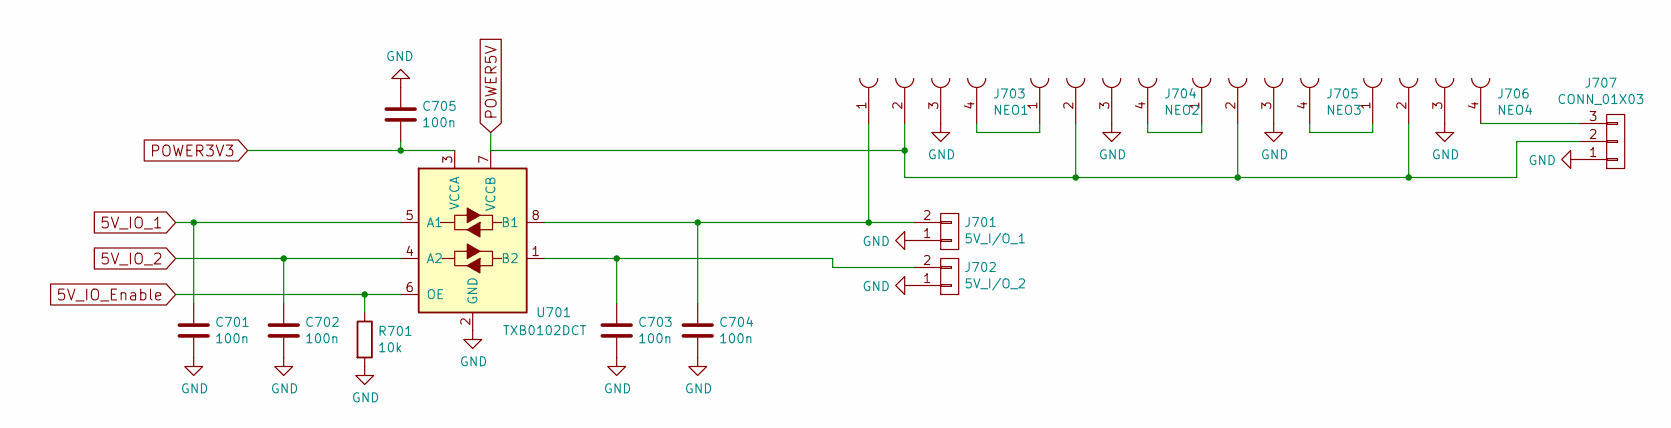
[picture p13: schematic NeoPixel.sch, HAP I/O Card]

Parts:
C701, C702, C703, C704, C705: 100n; C_0805
J701: 5V_I/O_1; Pin_Header_Straight_1x02_Pitch2.54mm
J702: 5V_I/O_2; Pin_Header_Straight_1x02_Pitch2.54mm
J703: NEO1; Pin_Header_Straight_1x04_Pitch1.27mm
J704: NEO2; Pin_Header_Straight_1x04_Pitch1.27mm
J705: NEO3; Pin_Header_Straight_1x04_Pitch1.27mm
J706: NEO4; Pin_Header_Straight_1x04_Pitch1.27mm
J707: CONN_01X03; Pin_Header_Straight_1x03_Pitch2.54mm
R701: 10k; R_0805
U701: TXB0102DCT; TSSOP-8_3x3mm_Pitch0.65mm

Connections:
5V_IO_1: C701.1, U701.5 (A1); also elsewhere on the board
5V_IO_2: C702.1, U701.4 (A2); also elsewhere on the board
5V_IO_Enable: R701.1, U701.6 (OE); also elsewhere on the board
Earth: C701.2, C702.2, C703.2, C704.2, C705.1, J701.1, J702.1, J703.3, J704.3, J705.3, J706.3, J707.1, R701.2, U701.2 (GND); also elsewhere on the board
unnamed: C703.1, J702.2, U701.1 (B2)
unnamed: C704.1, J701.2, J703.1, U701.8 (B1)
unnamed: J703.4, J704.1
unnamed: J704.4, J705.1
unnamed: J705.4, J706.1
unnamed: J706.4, J707.3
POWER3V3: C705.2, U701.3 (VCCA); also elsewhere on the board
POWER5V: J703.2, J704.2, J705.2, J706.2, J707.2, U701.7 (VCCB); also elsewhere on the board

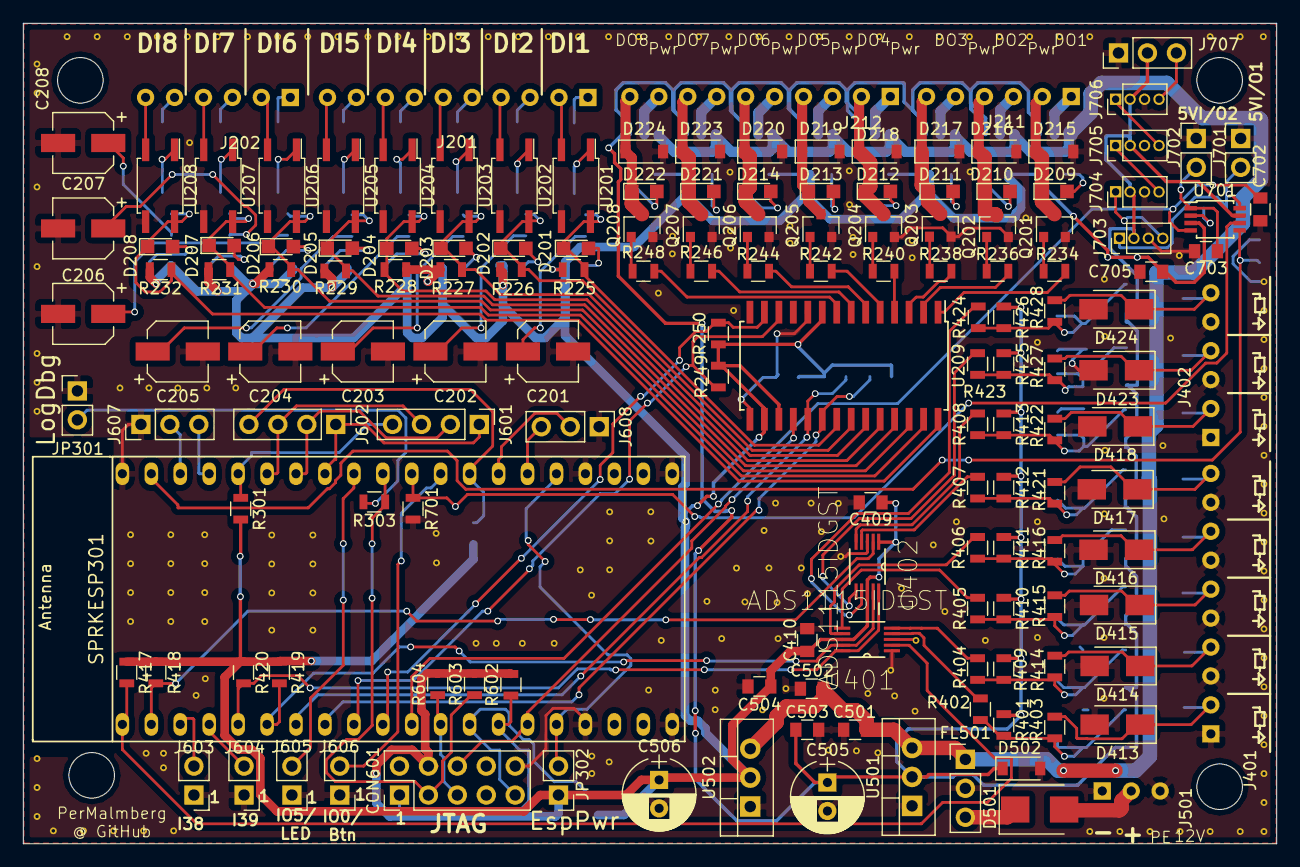
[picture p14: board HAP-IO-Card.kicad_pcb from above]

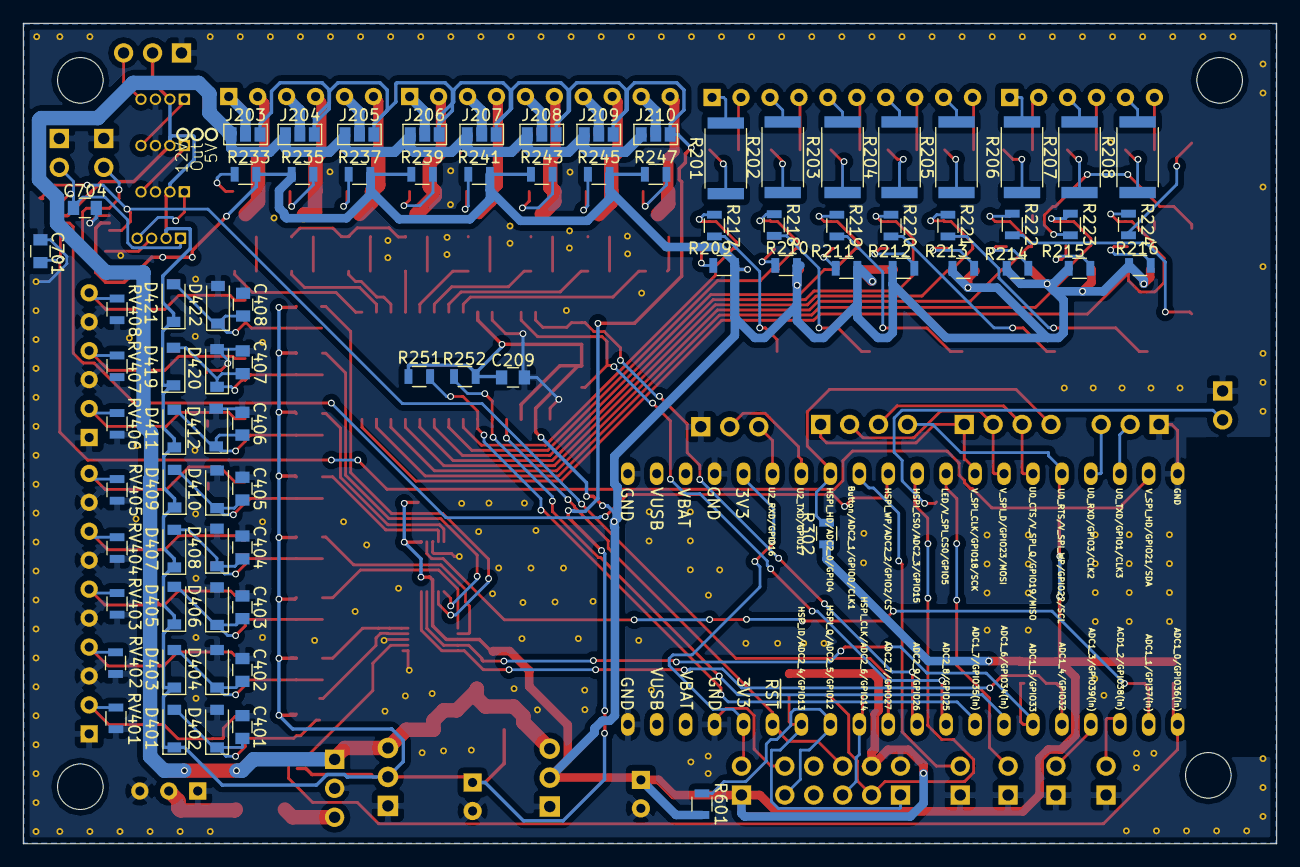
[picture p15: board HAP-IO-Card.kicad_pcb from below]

Board: 2 copper layers, 110.0 x 72.0 mm, 233 parts (79 on the bottom side), 155 nets.

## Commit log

2017-05-01 Started schematics
    [HAP-IO-Card.kicad_pcb, HAP-IO-Card.sch]
2017-05-03 ESP32 component and footprint
    [HAP-IO-Card.kicad_pcb, HAP-IO-Card.sch]
2017-05-12 More work
    [HAP-IO-Card.kicad_pcb, HAP-IO-Card.sch]
2017-05-13 Split into separate schemas
    [AnalogInputs.sch, DigitalInputs.sch, ESP32 Connections.sch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]
2017-05-16 Analog inputs
    [DigitalInputs.sch, ESP32 Connections.sch, HAP-IO-Card.kicad_pcb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]
2017-05-18 Added power supply
    [AnalogInputs.sch, DigitalInputs.sch, ESP32 Connections.sch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]
2017-05-21 Use I2C for I/O
    [AnalogInputs.sch, DigitalIO.sch, DigitalInputs.sch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]
2017-05-21 Removed old schema
    [DigitalInputs.sch]
2017-05-23 Reworked power-supply to provide 5V. Updated ESP-connections.
    [AnalogInputs.sch, DigitalIO.sch, ESP32 Connections.sch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]
2017-05-25 More layout
    [AnalogInputs.sch, DigitalIO.sch, ESP32 Connections.sch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]
2017-05-26 Commit before redoing layout
    [AnalogInputs.sch, DigitalIO.sch, ESP32 Connections.sch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]
2017-05-26 Remade layout
    [DigitalIO.sch, HAP-IO-Card.kicad_pcb, NeoPixel.sch]
2017-05-26 Before starting traces
    [HAP-IO-Card.kicad_pcb]
2017-05-28 Before reworking analog inputs.
    [AnalogInputs.sch, DigitalIO.sch, ESP32 Connections.sch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]
2017-05-28 Save with sensor inputs using digital potentiometer
    [AnalogInputs.sch, DigitalIO.sch, ESP32 Connections.sch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]
2017-06-03 Inputs reworked. New terminals
    [AnalogInputs.sch, DigitalIO.sch, ESP32 Connections.sch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]
2017-06-04 Halfway through routing - need better layout to prevent rats nest
    [DigitalIO.sch, ESP32 Connections.sch, HAP-IO-Card.kicad_pcb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]
2017-06-06 New sense input circuits. New layout
    [DigitalIO.sch, HAP-IO-Card.kicad_pcb, Headers.sch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]
2017-06-07 More routing
    [HAP-IO-Card.kicad_pcb, Headers.sch]
2017-06-10 Starting another routing pass
    [ESP32 Connections.sch, HAP-IO-Card.kicad_pcb, Headers.sch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]
2017-06-10 Everything routed. ERC Ok
    [ESP32 Connections.sch, HAP-IO-Card.kicad_pcb]
2017-06-10 Increased ground plane coverage
    [ESP32 Connections.sch, HAP-IO-Card.kicad_pcb]
2017-06-11 More groundplane
    [HAP-IO-Card.kicad_pcb]
2017-06-11 Increased width of 12V rail
    [HAP-IO-Card.kicad_pcb]
2017-06-11 Increased width of 3.3V rail
    [HAP-IO-Card.kicad_pcb]
2017-06-12 Removed via in pad
    [HAP-IO-Card.kicad_pcb]
2017-06-12 Fixed unconnected pad
    [HAP-IO-Card.kicad_pcb]
2017-06-12 Increased size of some 3.3V wires
    [HAP-IO-Card.kicad_pcb]
2017-06-13 Update capacitor values
    [NeoPixel.sch]
2017-06-13 Added pullups for JTAG
    [DigitalIO.sch, ESP32 Connections.sch, HAP-IO-Card.kicad_pcb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]
2017-06-13 Updated a few components and links
    [DigitalIO.sch, Powersupply.sch, SenseInputs.sch]
2017-06-14 Updated EMI component
    [DigitalIO.sch, ESP32 Connections.sch, HAP-IO-Card.kicad_pcb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]
2017-06-21 Updated 12V traces
    [HAP-IO-Card.kicad_pcb]
